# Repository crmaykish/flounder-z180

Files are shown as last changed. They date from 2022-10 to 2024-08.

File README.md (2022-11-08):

# Flounder Z180 Computer

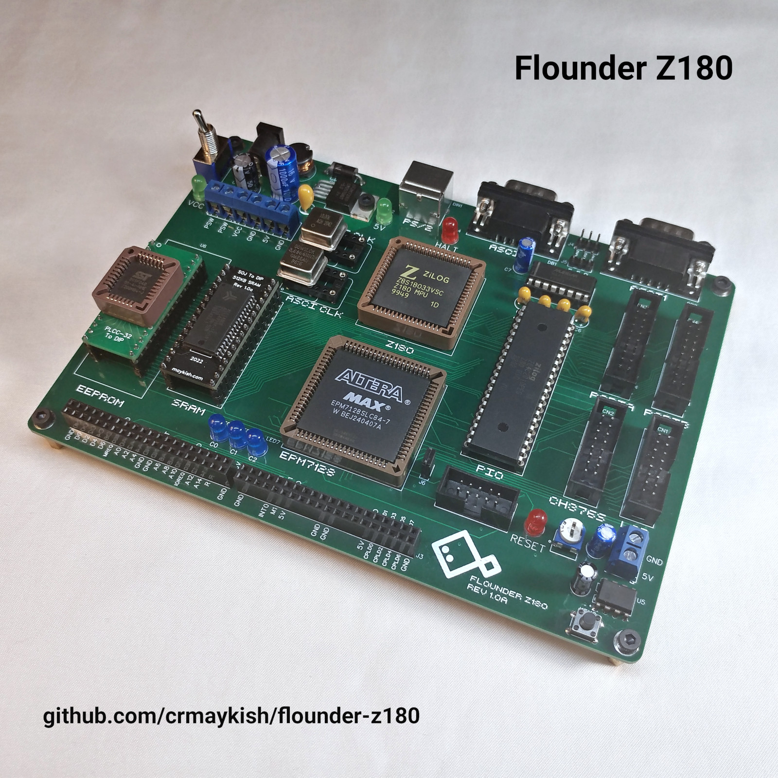
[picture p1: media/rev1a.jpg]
Flounder Z180 Computer


Flounder is a standalone single-board computer built around the Zilog Z180 processor.

It features:
- Clock speed up to 33 MHz (overclockable to 40+)
- 512 KB of both ROM and SRAM
- Two RS-232 serial ports
- 16 GPIO pins
- PS/2 keyboard interface
- Support for 40x4 character LCD display
- CH376S USB storage

## Hardware
An Altera EPM7064 (or EPM7128) 84-pin CPLD provides glue logic and additional interfacing options. An expansion header breaks out address, data, and control lines to support additional hardware development.

## Software
All software development is done in C with the z88dk toolkit. Programs are flashed to and run from the EEPROM.

A hardware monitor program gives access to basic memory and I/O operations including: peek, poke, and memdump.

## Resources
1. [Hackaday Project](https://hackaday.io/project/187588-flounder-z180-sbc)
2. [Z8S180 Datasheet](http://www.zilog.com/docs/z180/z8s180ps.pdf)
3. [z88dk](https://github.com/z88dk/z88dk)

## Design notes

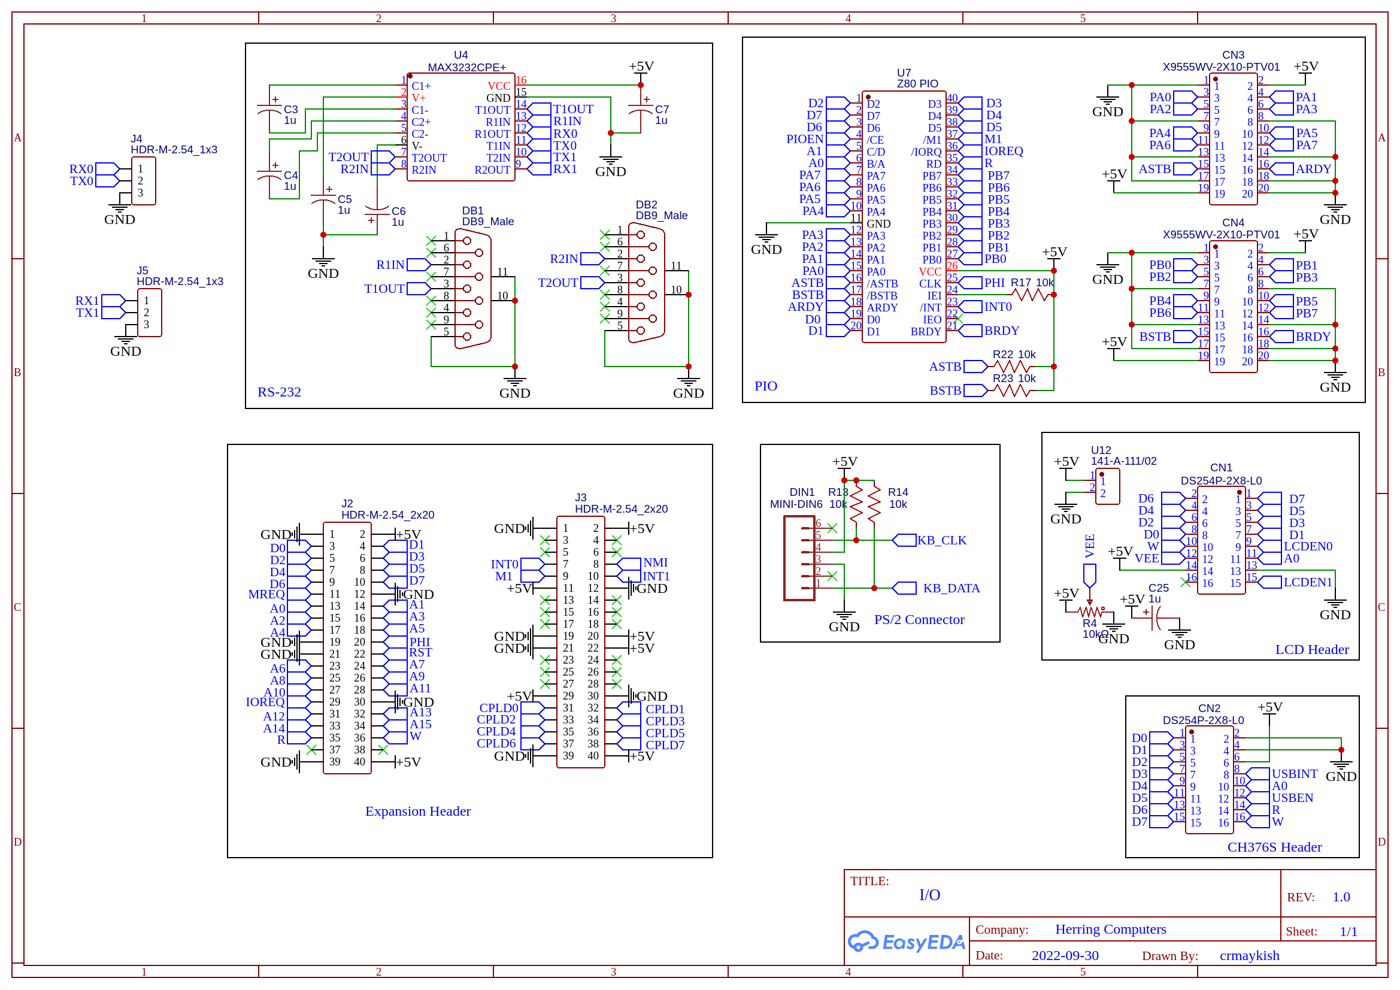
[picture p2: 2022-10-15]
releases/rev1.0a/I_O.png

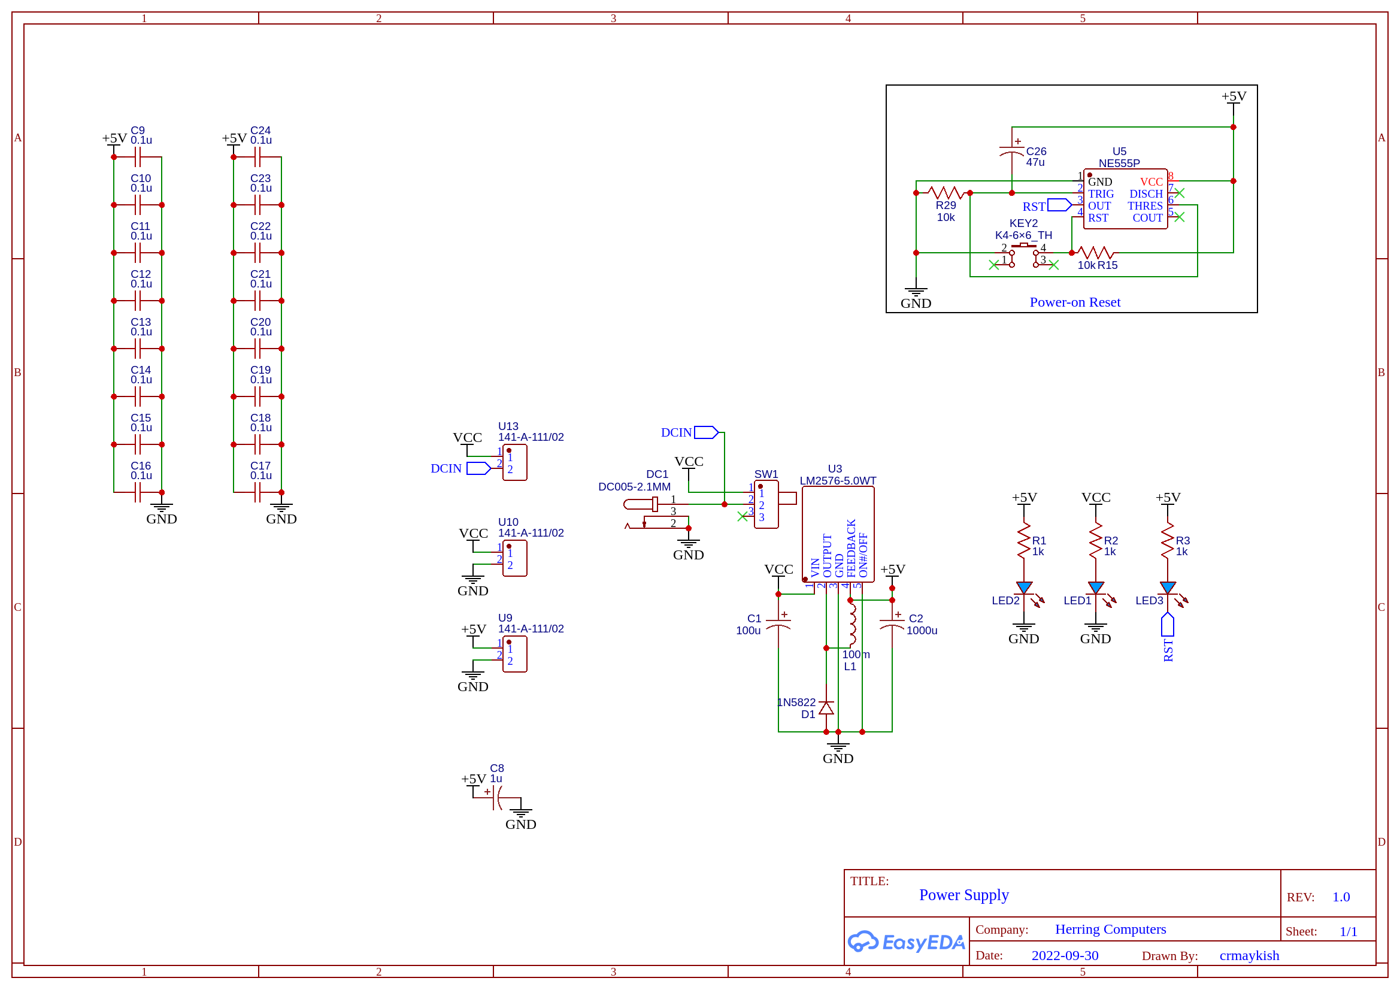
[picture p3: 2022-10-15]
releases/rev1.0a/Power.png

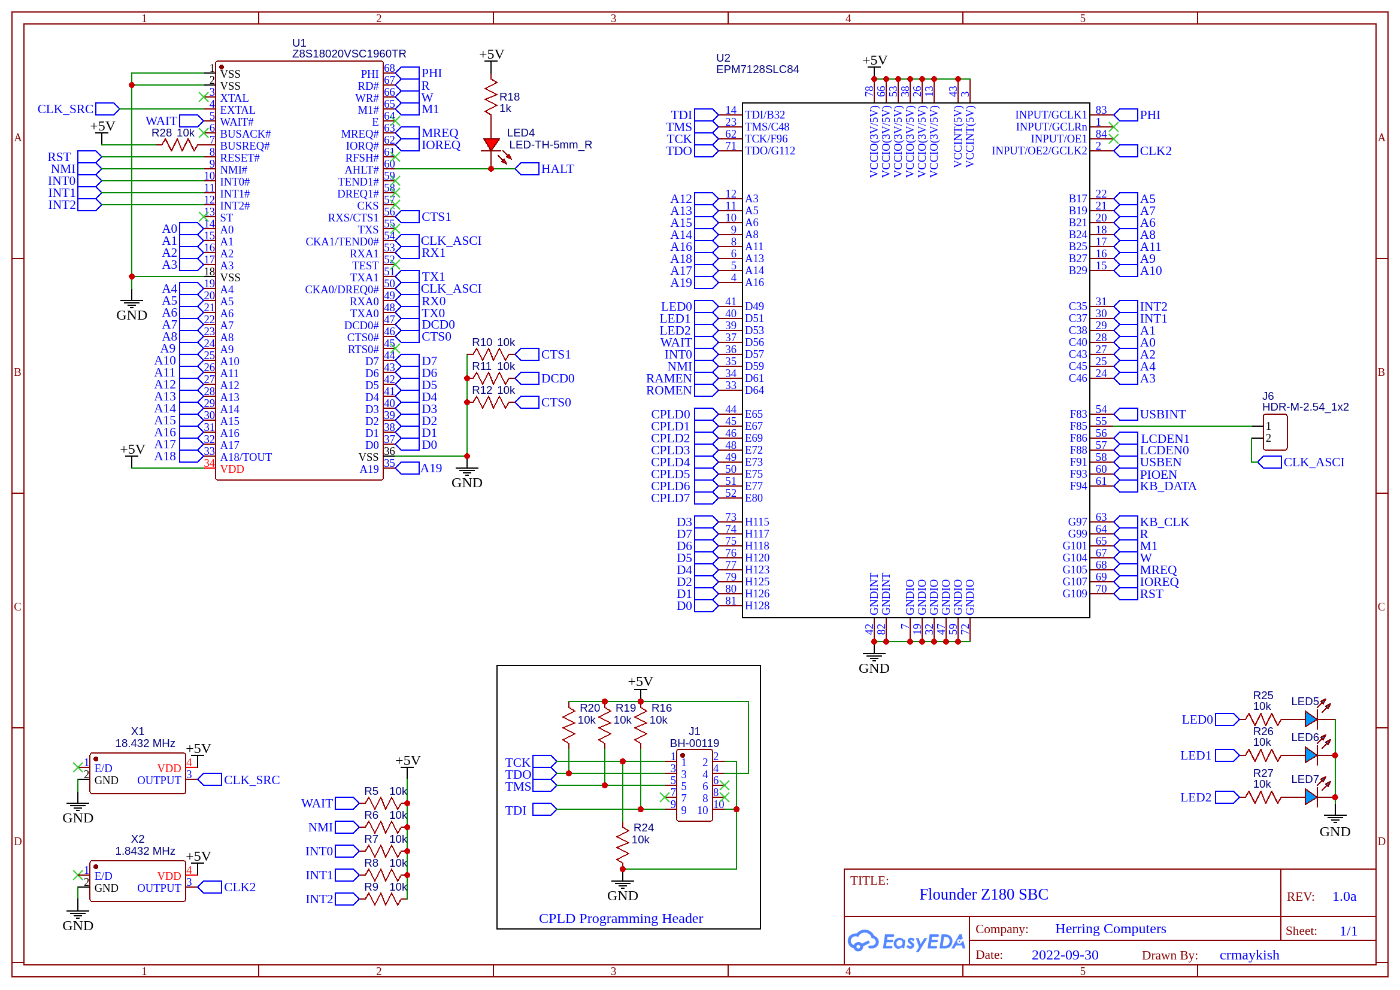
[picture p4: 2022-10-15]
releases/rev1.0a/CPU_CPLD.png

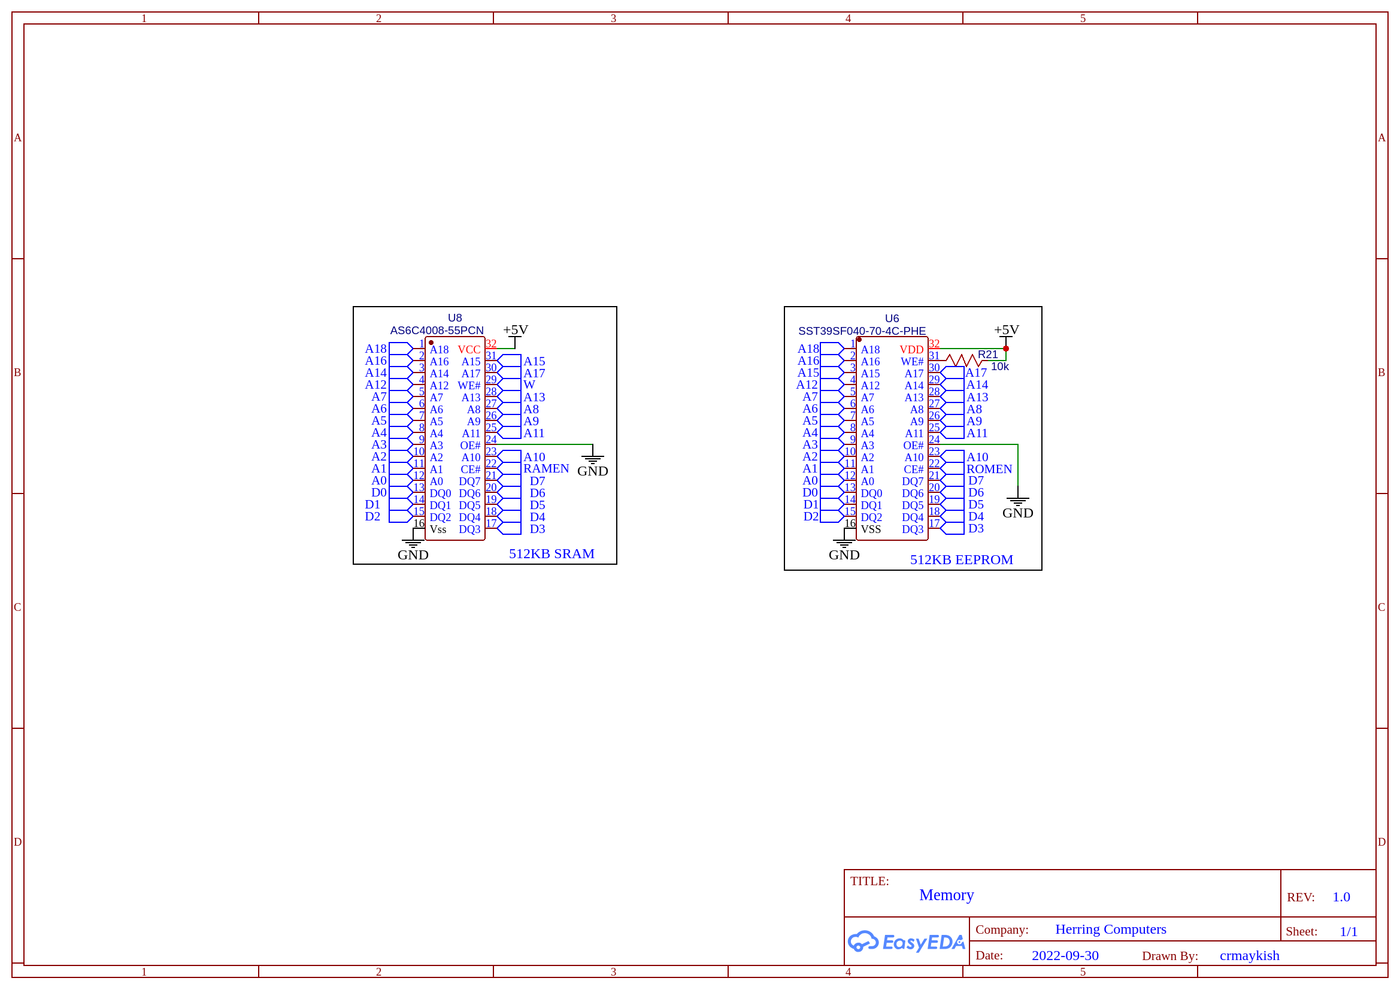
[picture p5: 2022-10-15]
releases/rev1.0a/Memory.png

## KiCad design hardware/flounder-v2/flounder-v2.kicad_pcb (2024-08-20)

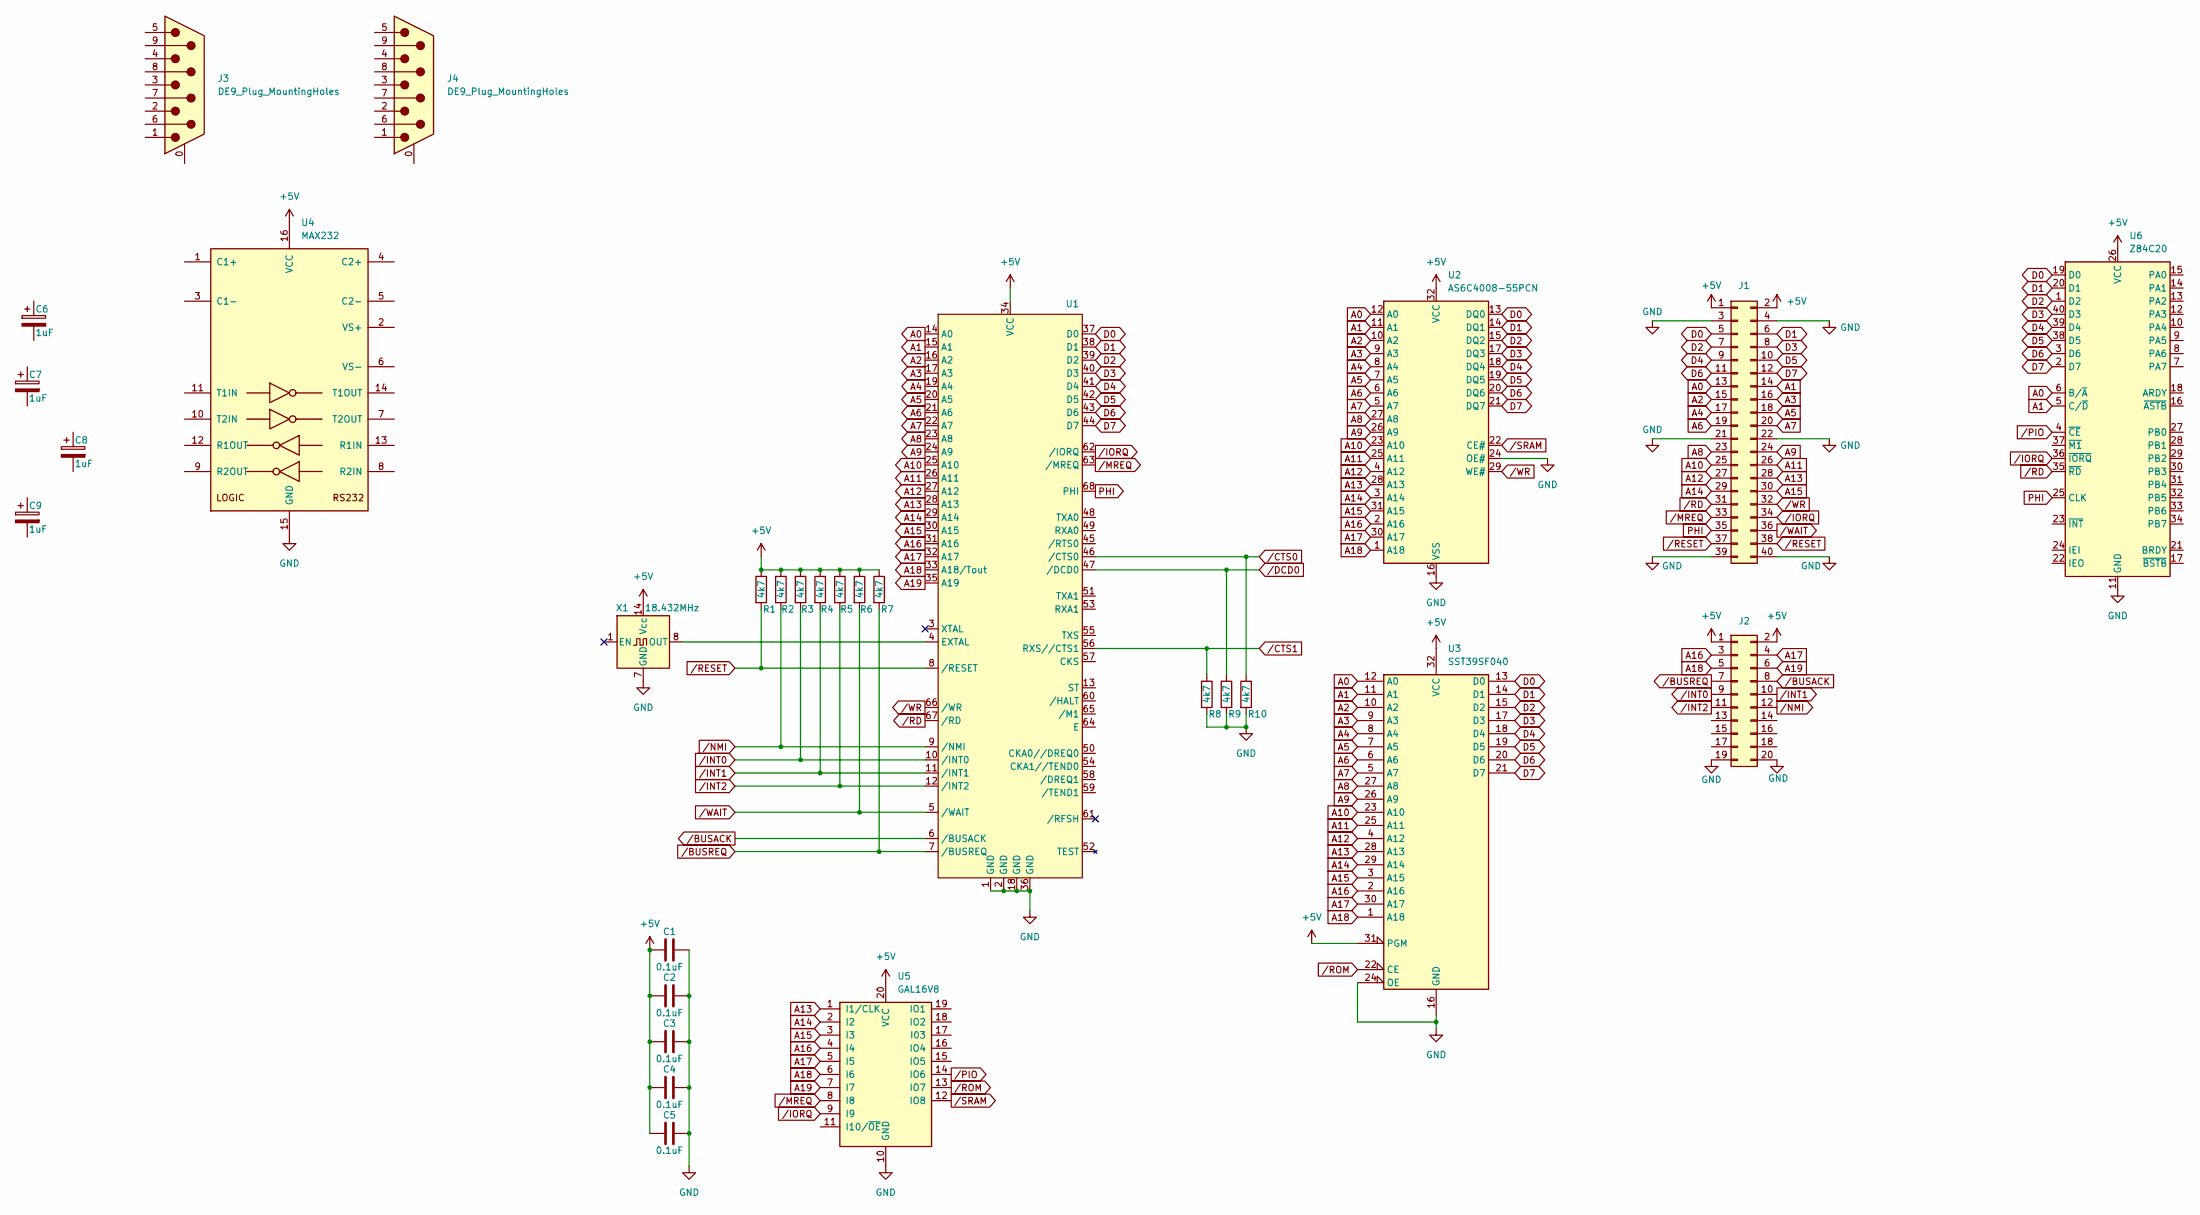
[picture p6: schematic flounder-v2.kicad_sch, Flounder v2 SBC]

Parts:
C1, C2, C3, C4, C5: 0.1uF; C_Disc_D5.0mm_W2.5mm_P5.00mm
C6, C7, C8, C9: 1uF; CP_Radial_D5.0mm_P2.50mm
J1: Conn_02x20_Odd_Even; PinHeader_2x20_P2.54mm_Vertical
J2: Conn_02x10_Odd_Even; PinHeader_2x10_P2.54mm_Vertical
J3, J4: DE9_Plug_MountingHoles; DSUB-9_Male_Horizontal_P2.77x2.84mm_EdgePinOffset7.70mm_Hou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
R1, R2, R3, R4, R5, R6, R7, R8, R9, R10: 4k7; R_Axial_DIN0207_L6.3mm_D2.5mm_P7.62mm_Horizontal
U1: Z8S180; PLCC-68_THT-Socket
U2: AS6C4008-55PCN; DIP-32_W15.24mm_Socket
U3: SST39SF040; DIP-32_W15.24mm_Socket
U4: MAX232; DIP-16_W7.62mm_Socket
U5: GAL16V8; DIP-20_W7.62mm_Socket
U6: Z84C20; DIP-40_W15.24mm_Socket
X1: 18.432MHz; Oscillator_DIP-14

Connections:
+5V: C1.1, C2.1, C3.1, C4.1, C5.1, J1.1, J1.2, J2.1, J2.2, R1.1, R2.1, R3.1, R4.1, R5.1, R6.1, R7.1, U1.34 (VCC), U2.32 (VCC), U3.31 (PGM), U3.32 (VCC), U4.16 (VCC), U5.20 (VCC), U6.26 (VCC), X1.14 (Vcc)
A0: J1.13, U1.14 (A0), U2.12 (A0), U3.12 (A0), U6.6 (B/~A)
A1: J1.14, U1.15 (A1), U2.11 (A1), U3.11 (A1), U6.5 (C/~D)
A2: J1.15, U1.16 (A2), U2.10 (A2), U3.10 (A2)
A3: J1.16, U1.17 (A3), U2.9 (A3), U3.9 (A3)
A4: J1.17, U1.19 (A4), U2.8 (A4), U3.8 (A4)
A5: J1.18, U1.20 (A5), U2.7 (A5), U3.7 (A5)
A6: J1.19, U1.21 (A6), U2.6 (A6), U3.6 (A6)
A7: J1.20, U1.22 (A7), U2.5 (A7), U3.5 (A7)
A8: J1.23, U1.23 (A8), U2.27 (A8), U3.27 (A8)
A9: J1.24, U1.24 (A9), U2.26 (A9), U3.26 (A9)
A10: J1.25, U1.25 (A10), U2.23 (A10), U3.23 (A10)
A11: J1.26, U1.26 (A11), U2.25 (A11), U3.25 (A11)
A12: J1.27, U1.27 (A12), U2.4 (A12), U3.4 (A12)
A13: J1.28, U1.28 (A13), U2.28 (A13), U3.28 (A13), U5.1 (I1/CLK)
A14: J1.29, U1.29 (A14), U2.3 (A14), U3.29 (A14), U5.2 (I2)
A15: J1.30, U1.30 (A15), U2.31 (A15), U3.3 (A15), U5.3 (I3)
A16: J2.3, U1.31 (A16), U2.2 (A16), U3.2 (A16), U5.4 (I4)
A17: J2.4, U1.32 (A17), U2.30 (A17), U3.30 (A17), U5.5 (I5)
A18: J2.5, U1.33 (A18/Tout), U2.1 (A18), U3.1 (A18), U5.6 (I6)
A19: J2.6, U1.35 (A19), U5.7 (I7)
D0: J1.5, U1.37 (D0), U2.13 (DQ0), U3.13 (D0), U6.19 (D0)
D1: J1.6, U1.38 (D1), U2.14 (DQ1), U3.14 (D1), U6.20 (D1)
D2: J1.7, U1.39 (D2), U2.15 (DQ2), U3.15 (D2), U6.1 (D2)
D3: J1.8, U1.40 (D3), U2.17 (DQ3), U3.17 (D3), U6.40 (D3)
D4: J1.9, U1.41 (D4), U2.18 (DQ4), U3.18 (D4), U6.39 (D4)
D5: J1.10, U1.42 (D5), U2.19 (DQ5), U3.19 (D5), U6.38 (D5)
D6: J1.11, U1.43 (D6), U2.20 (DQ6), U3.20 (D6), U6.3 (D6)
D7: J1.12, U1.44 (D7), U2.21 (DQ7), U3.21 (D7), U6.2 (D7)
GND: C1.2, C2.2, C3.2, C4.2, C5.2, J1.3, J1.4, J1.21, J1.22, J1.39, J1.40, J2.19, J2.20, R8.2, R9.2, R10.2, U1.1 (GND), U1.2 (GND), U1.18 (GND), U1.36 (GND), U2.16 (VSS), U2.24 (OE#), U3.16 (GND), U3.24 (OE), U4.15 (GND), U5.10 (GND), U6.11 (GND), X1.7 (GND)
unnamed: U1.4 (EXTAL), X1.8 (OUT)
PHI: J1.35, U1.68 (PHI), U6.25 (CLK)
/BUSACK: J2.8, U1.6 (/BUSACK)
/BUSREQ: J2.7, R7.2, U1.7 (/BUSREQ)
/CTS0: R10.1, U1.46 (/CTS0)
/CTS1: R8.1, U1.56 (RXS//CTS1)
/DCD0: R9.1, U1.47 (/DCD0)
/INT0: J2.9, R3.2, U1.10 (/INT0)
/INT1: J2.10, R4.2, U1.11 (/INT1)
/INT2: J2.11, R5.2, U1.12 (/INT2)
/IORQ: J1.34, U1.62 (/IORQ), U5.9 (I9), U6.36 (~IORQ)
/MREQ: J1.33, U1.63 (/MREQ), U5.8 (I8)
/NMI: J2.12, R2.2, U1.9 (/NMI)
/PIO: U5.14 (IO6), U6.4 (~CE)
/RD: J1.31, U1.67 (/RD), U6.35 (~RD)
/RESET: J1.37, J1.38, R1.2, U1.8 (/RESET)
/ROM: U3.22 (CE), U5.13 (IO7)
/SRAM: U2.22 (CE#), U5.12 (IO8)
/WAIT: J1.36, R6.2, U1.5 (/WAIT)
/WR: J1.32, U1.66 (/WR), U2.29 (WE#)

Board: 2 copper layers, 30 parts (0 on the bottom side), 50 nets, no tracks yet.

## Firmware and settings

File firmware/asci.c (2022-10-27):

#include "asci.h"
#include <stdlib.h>
#include <z180.h>
#include "flounder.h"

void asci0_putc(char a)
{
    while ((z180_inp(STAT0) & 0b00000010) == 0)
    {
    }

    z180_outp(TDR0, a);
}

char asci0_getc()
{
    while ((z180_inp(STAT0) & 0b10000000) == 0)
    {
    }

    return z180_inp(RDR0);
}

void asci1_putc(char a)
{
    while ((z180_inp(STAT1) & 0b00000010) == 0)
    {
    }

    z180_outp(TDR1, a);
}

char asci1_getc()
{
    while ((z180_inp(STAT1) & 0b10000000) == 0)
    {
    }

    return z180_inp(RDR1);
}

void uart_print(char *s)
{
    char i = 0;
    char c = s[i];

    while (c != 0)
    {
        asci1_putc(c);
        i++;
        c = s[i];
    }
}

void uart_print_dec(uint32_t n)
{
    char buffer[11] = {0};

    utoa((unsigned int)n, buffer, 10);
    uart_print(buffer);
}

void uart_print_hex(uint32_t n)
{
    char buffer[11] = {0};

    if (n < 0x10)
    {
        asci1_putc('0');
    }

    utoa((unsigned int)n, buffer, 16);
    uart_print(buffer);
}

uint16_t uart_readline(char *buffer, bool echo)
{
    char in = 0;
    uint16_t i = 0;

    while (in != 0x0A && in != 0x0D)
    {
        in = asci1_getc();

        if (echo)
        {
            asci1_putc(in);
        }

        buffer[i] = in;
        i++;
    }

    buffer[i] = 0;

    return i;
}

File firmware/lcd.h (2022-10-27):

#ifndef LCD_H
#define LCD_H

#include <stdint.h>

#define LCD_COMMAND0 0x6000
#define LCD_DATA0 0x6001
#define LCD_COMMAND1 0x8000
#define LCD_DATA1 0x8001

#define LCD_COMMAND_SETMODE 0x3F
#define LCD_COMMAND_CURSOR_ON 0x0F
#define LCD_COMMAND_CLEAR_DISPLAY 1
#define LCD_COMMAND_CURSOR_HOME 2

#define LCD_BUSY_FLAG 0b10000000
#define LCD_ADDR_MASK 0b01111111

#define LCD_DISPLAY_COMMAND 0b00001000
#define LCD_DISPLAY_ON 0b100
#define LCD_CURSOR_ON 0b10
#define LCD_CURSOR_BLINK 0b1

void lcd_init();
void lcd_busy_wait(uint8_t controller);
void lcd_putc(char c);
void lcd_print(char *s);
void lcd_clear();
void lcd_print_hex(uint32_t n);
uint8_t get_address();

#endif

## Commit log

2021-11-23 Low speed ROM emulation using the Pi Pico
2021-11-23 Add first schematic diagram
2021-11-23 Rewired board without level shifters
2021-11-23 Pi Pico is emulating memory writes
2021-11-26 More UART testing
2021-11-29 Internal UART running at 115200 baud at with 100 kHz clock source
2021-11-29 RAM writes emulated with Pico
2021-11-29 Remove old assembly code
2022-10-04 Add user LED outputs to CPLD
2022-10-04 Connected SRAM write pin directly to CPU /WR
2022-10-07 Periodic timer interrupts triggered by PRT0
2022-10-09 Interrupts kind of working again
2022-10-09 Interrupts are running, but conflicting with peripherals
2022-10-09 Interrupts fully controlled by z88dk and ISRs in C
2022-10-15 Rev 1.0a schematics and gerber files
2022-10-25 Start of decovder for 84 pin CPLD
2022-10-27 Interrupts, ASCI clock, and LCD working on PCB rev 1.0a
2022-10-28 Fixed CPLD conflict with other I/O devices
2022-10-28 CPLD LEDs are now addressable by the CPU
2022-11-07 Updated timer and CPLD LEDs
2024-08-20 Stubbed out Flounder v2 schematic
    [flounder-v2.kicad_pcb, flounder-v2.kicad_sch]
2024-08-20 Add PIO to v2
    [flounder-v2.kicad_pcb, flounder-v2.kicad_sch]
